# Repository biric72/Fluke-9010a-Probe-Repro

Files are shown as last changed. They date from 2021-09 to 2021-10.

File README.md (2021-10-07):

  # Fluke-9010a-Probe-Repro-Package
 Fluke 9000A Probe Repro Project for the 9010A Microsystem Troubleshooter

Since these have become virtually unobtainable, I decided to try my best to make a repro which is as close as possible to the original’s physical appearance and electrical layout.

This project includes

- Gerber archive to order the PCB’s with your manufacturer of choice
- The KiCAD files of the board if you want to make any changes
- Freecad file of the probe’s case:
    - I tried to keep the the case as close as possible to the original, but also printable with a ‚normal‘ 3d printer (see manual) so internally it is a bit simplified.
    - not all sketches are fully constraint, I did not want to spent an unnecessary amount of time.
    - I printed the case with black PLA, the windows with clear/natural PLA and the cable guide with flexible TPU which worked quite well. 
- A build manual which includes a BOM and part numbers for DigiKey.

To complete the build you will need moderate SMD soldering and tinkering skills as well as a bit of patience.

Of course I cannot be responsible  for any damage you do to yourself or your fluke mainframe; however, I have built 2 probes and they seem to work flawlessly.

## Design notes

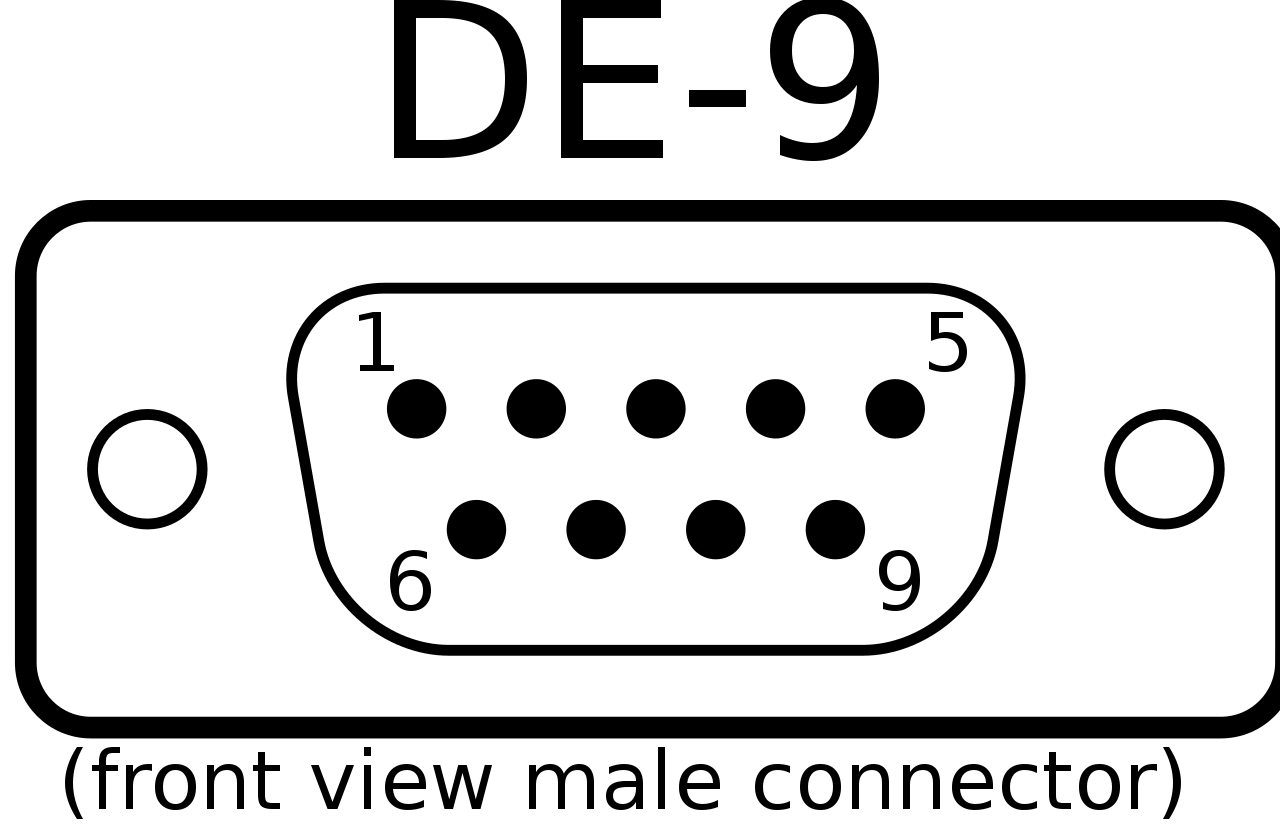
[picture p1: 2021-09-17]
Kicad/Fluke 9010a Probe/D-Sub9_(front_view_of_male_connector_with_pin_numbers).svg.png

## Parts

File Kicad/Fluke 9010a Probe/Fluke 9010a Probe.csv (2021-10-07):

Id | Designator | Package | Quantity | Designation | Supplier and ref
1 | G*** | Zubline_very_very_small | 1 | LOGO
2 | Tip | TestPoint_THTPad_4.0x4.0mm_Drill2.0mm | 1 | Probe Tip
3 | A7 | FlukeProbe_9Pin_3 | 1 | ProbeConn
4 | CR2,CR1 | D_1806_4516Metric | 2 | 1N4448
5 | C1 | C_0805_2012Metric_Pad1.15x1.40mm_HandSolder | 1 | 33 pF 100V
6 | C2,C3 | C_0805_2012Metric_Pad1.15x1.40mm_HandSolder | 2 | .39uF 50V
7 | D1(Green) | LED_D3.0mm | 1 | GRN
8 | D2(Red) | LED_D3.0mm | 1 | RED
9 | Q1 | SOT-23_Handsoldering | 1 | MMBT3906
10 | Q2 | SOT-23_Handsoldering | 1 | MMBT3904
11 | R1 | D_0805_2012Metric_Pad1.15x1.40mm_HandSolder | 1 | 205K 1%
12 | R2 | D_0805_2012Metric_Pad1.15x1.40mm_HandSolder | 1 | 220R
13 | R3 | D_0805_2012Metric_Pad1.15x1.40mm_HandSolder | 1 | 100K 1%
14 | R4 | D_0805_2012Metric_Pad1.15x1.40mm_HandSolder | 1 | 68K 1/8W
15 | R5,R6 | D_0805_2012Metric_Pad1.15x1.40mm_HandSolder | 2 | 330R

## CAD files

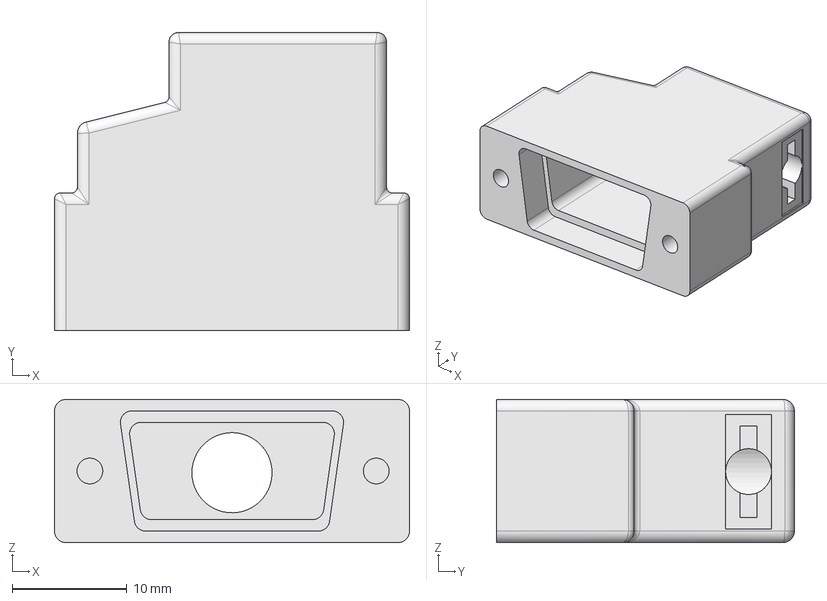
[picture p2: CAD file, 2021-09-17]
Freecad/ConnectorHousing010.FCStd
31.0 x 26.0 x 12.5 mm

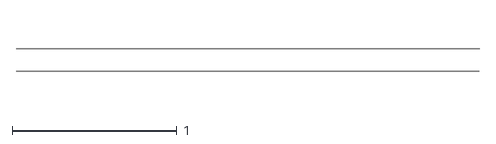
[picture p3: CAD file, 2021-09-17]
Kicad/Fluke 9010a Probe/Decal001.dxf
2.81 x 0.135

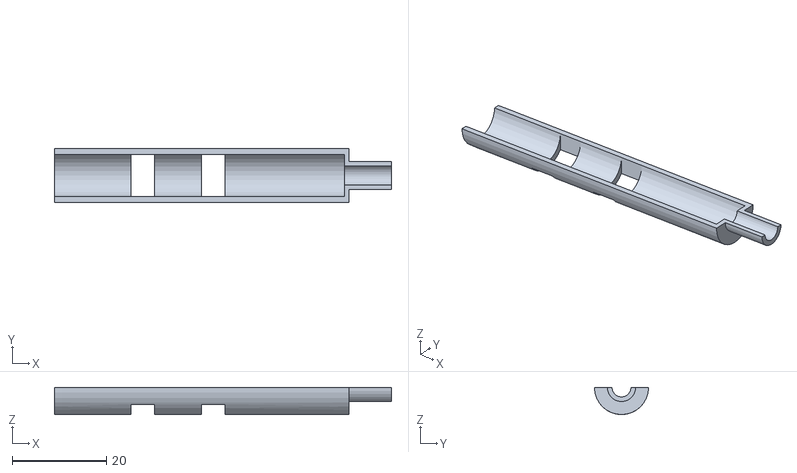
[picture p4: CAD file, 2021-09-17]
STL/Back.stl
71.5 x 11.5 x 5.75

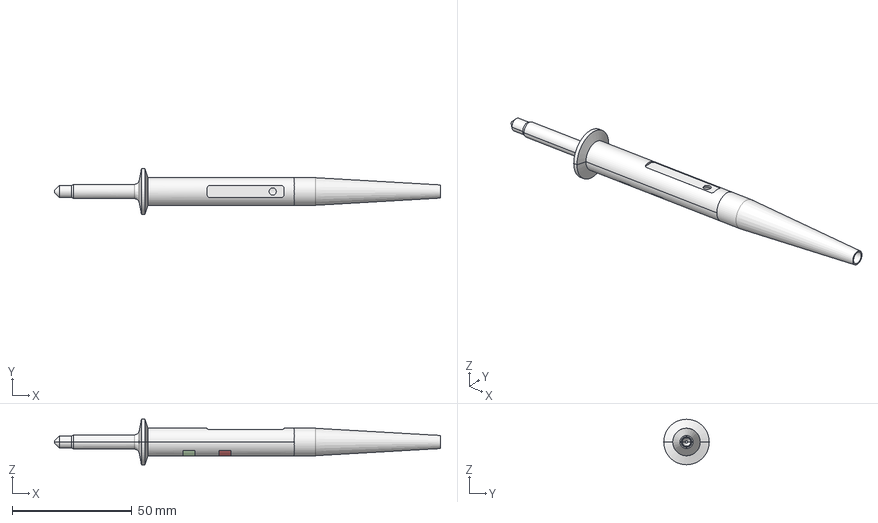
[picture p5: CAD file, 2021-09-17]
Freecad/FlukeProbe040_Final.FCStd
161.0 x 19.0 x 19.0 mm
Half
Front
Back
RedWindow
GreenWindow
CableGuide

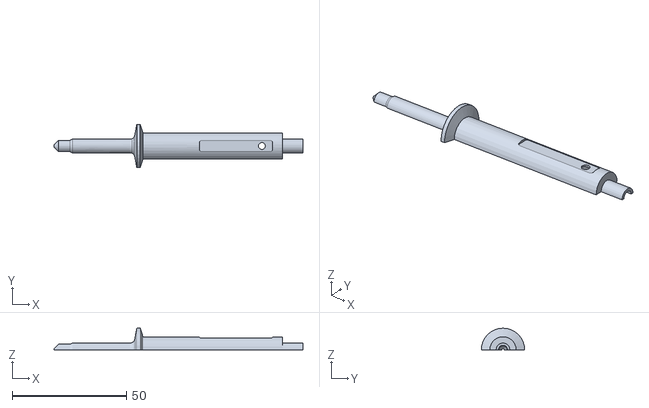
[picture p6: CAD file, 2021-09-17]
STL/Half.stl
109.0 x 19.0 x 9.50

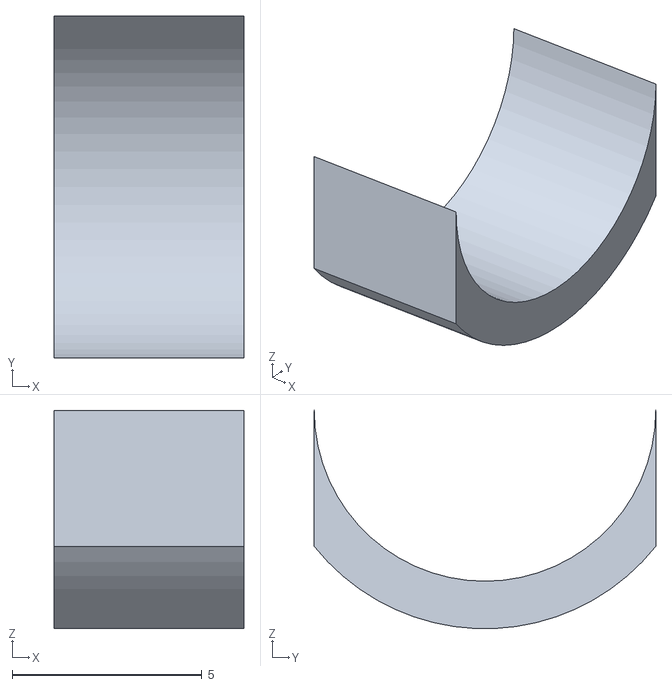
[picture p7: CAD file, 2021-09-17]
STL/Window.stl
5.00 x 9.00 x 5.74

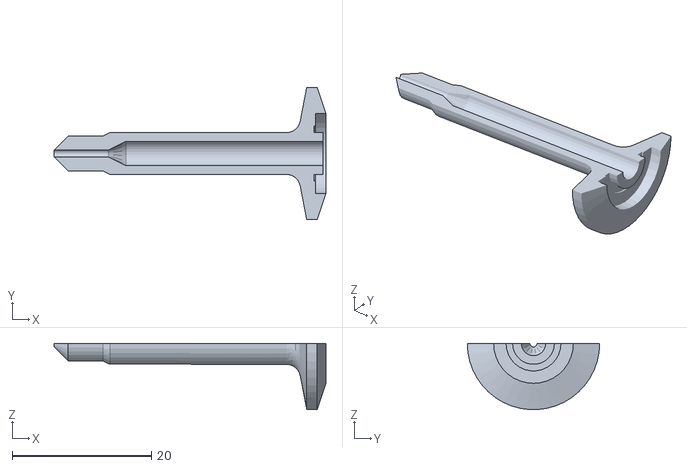
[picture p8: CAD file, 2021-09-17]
STL/Front.stl
39.0 x 19.0 x 9.48

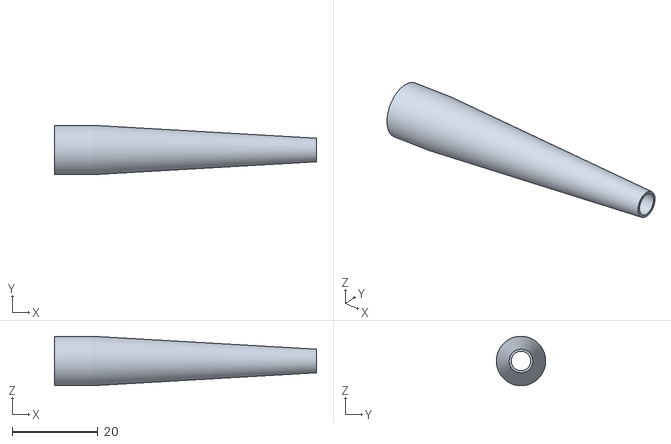
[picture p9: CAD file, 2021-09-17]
STL/CableGuide.stl
61.0 x 11.5 x 11.5

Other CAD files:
STL/ConnectorHousing.stl

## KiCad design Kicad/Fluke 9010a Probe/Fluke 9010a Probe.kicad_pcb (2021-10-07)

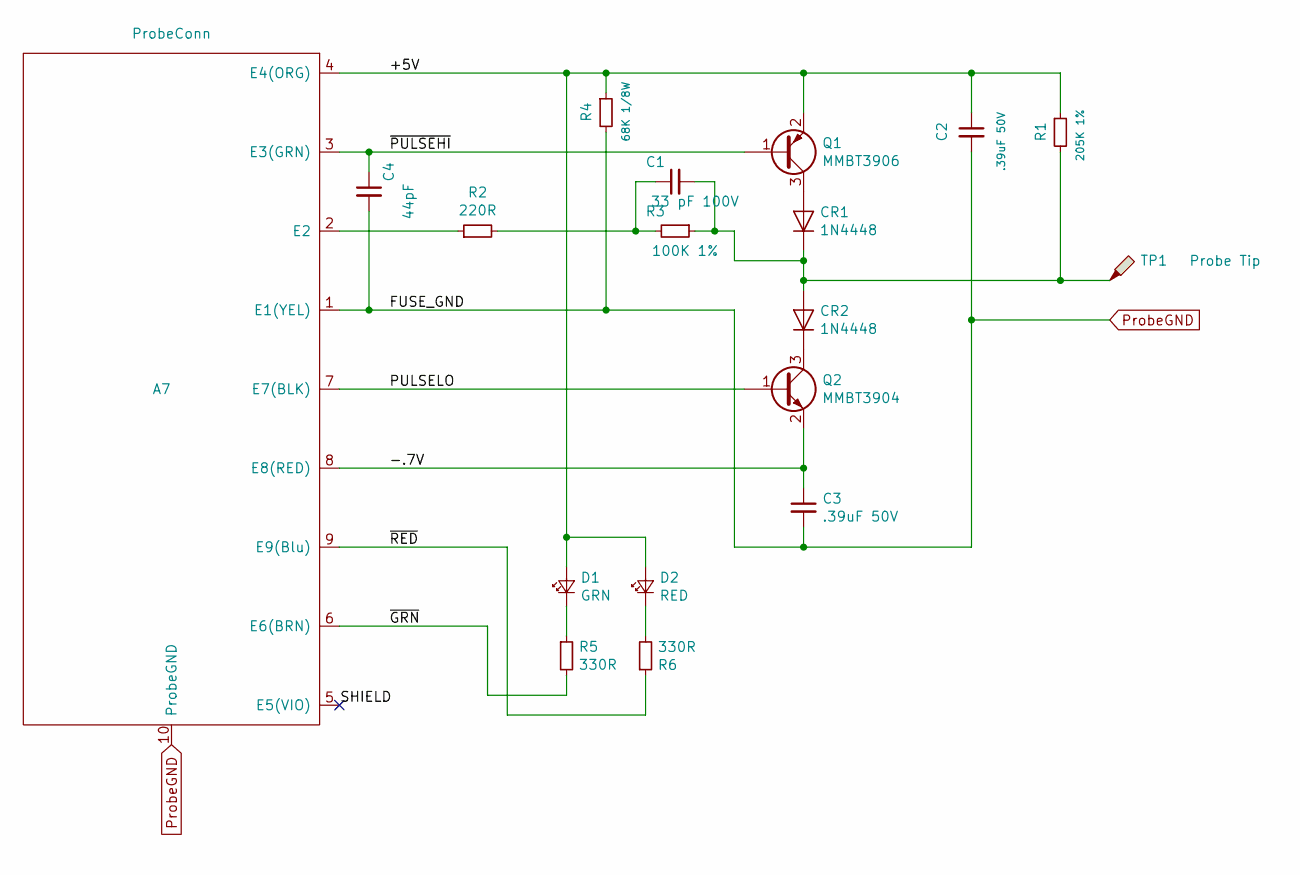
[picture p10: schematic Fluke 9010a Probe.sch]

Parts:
A7: ProbeConn; FlukeProbe_9Pin_3
C1: 33 pF 100V; C_0805_2012Metric_Pad1.15x1.40mm_HandSolder
C2, C3: .39uF 50V; C_0805_2012Metric_Pad1.15x1.40mm_HandSolder
C4: 44pF; C_0805_2012Metric_Pad1.15x1.40mm_HandSolder
CR1, CR2: 1N4448; D_1806_4516Metric
D1: GRN; LED_D3.0mm
D2: RED; LED_D3.0mm
Q1: MMBT3906; SOT-23_Handsoldering
Q2: MMBT3904; SOT-23_Handsoldering
R1: 205K 1%; D_0805_2012Metric_Pad1.15x1.40mm_HandSolder
R2: 220R; D_0805_2012Metric_Pad1.15x1.40mm_HandSolder
R3: 100K 1%; D_0805_2012Metric_Pad1.15x1.40mm_HandSolder
R4: 68K 1/8W; D_0805_2012Metric_Pad1.15x1.40mm_HandSolder
R5, R6: 330R; D_0805_2012Metric_Pad1.15x1.40mm_HandSolder
TP1: Probe Tip; TestPoint_THTPad_3.0x3.0mm_Drill1.5mm

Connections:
/+5V: A7.4 (E4(ORG)), C2.1, D1.2 (A), D2.2 (A), Q1.2 (E), R1.1, R4.1
/-.7V: A7.8 (E8(RED)), C3.1, Q2.2 (E)
/PULSELO: A7.7 (E7(BLK)), Q2.1 (B)
/SHIELD: A7.5 (E5(VIO))
/~GRN: A7.6 (E6(BRN)), R5.2
/~PULSEHI: A7.3 (E3(GRN)), C4.1, Q1.1 (B)
/~RED: A7.9 (E9(Blu)), R6.1
unnamed: A7.2 (E2), R2.1
unnamed: C1.1, R2.2, R3.2
unnamed: C1.2, CR1.1 (K), CR2.2 (A), R1.2, R3.1, TP1.1
unnamed: CR1.2 (A), Q1.3 (C)
unnamed: CR2.1 (K), Q2.3 (C)
unnamed: D1.1 (K), R5.1
unnamed: D2.1 (K), R6.2
ProbeGND: A7.1 (E1(YEL)), A7.10 (ProbeGND), C2.2, C3.2, C4.2, R4.2

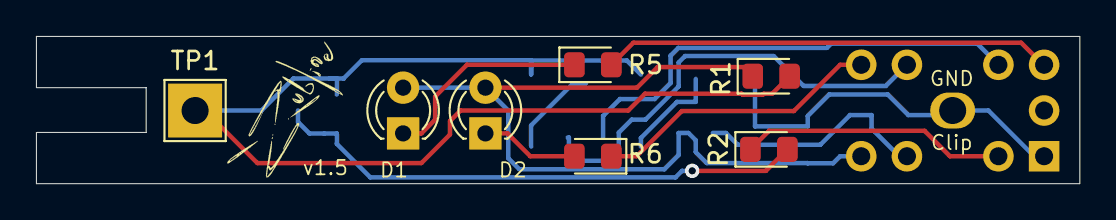
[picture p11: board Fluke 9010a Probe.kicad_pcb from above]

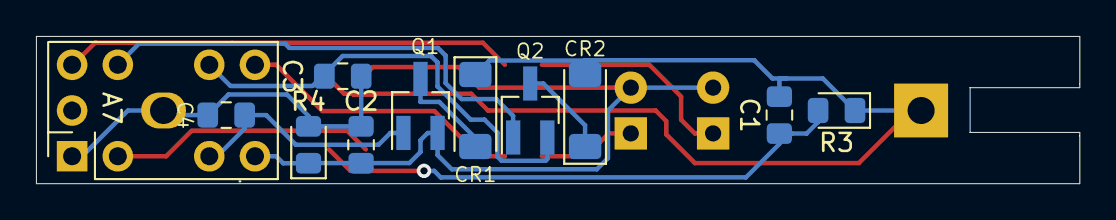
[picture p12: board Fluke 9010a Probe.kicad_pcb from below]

Board: 2 copper layers, 58.0 x 8.2 mm, 18 parts (11 on the bottom side), 14 nets.
